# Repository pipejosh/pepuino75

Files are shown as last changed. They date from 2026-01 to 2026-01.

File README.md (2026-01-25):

## Introducing the pepuino75

This is the pepuino75, a 75 percent keyboard, featuring my custom microcontroler, the pepuinoNanoV1 (https://github.com/pipejosh/pepuinoNano-devBoard), this keyboard also features a rotary encoder, design to make it as compact as possible, without lossing any of its features!

### RENDER
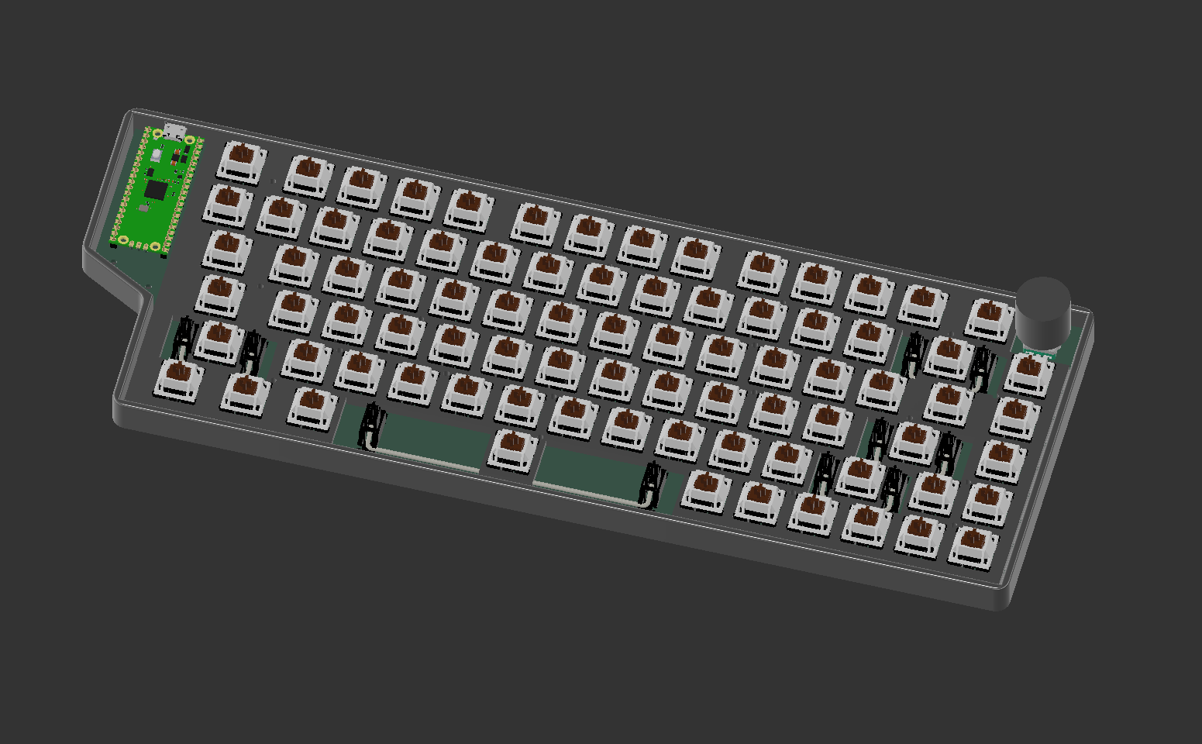
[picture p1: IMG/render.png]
 
### SCHEMATIC
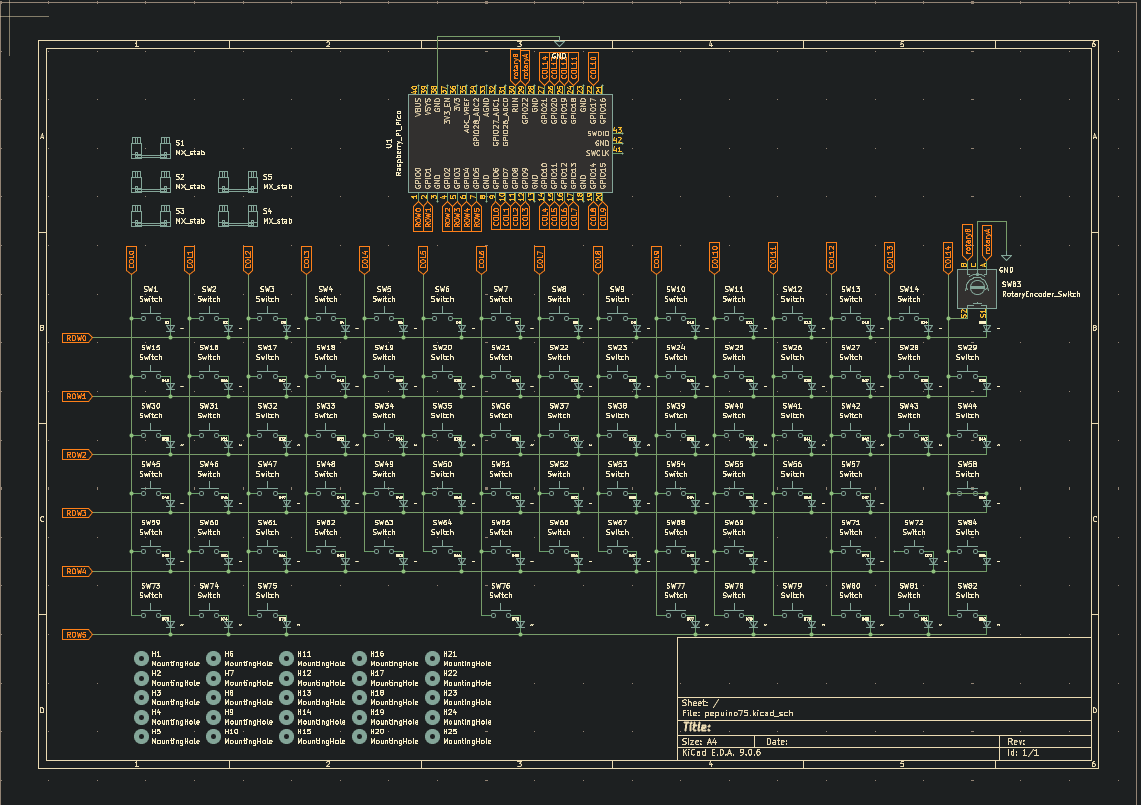
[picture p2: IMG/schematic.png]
schematic
 
### PCB
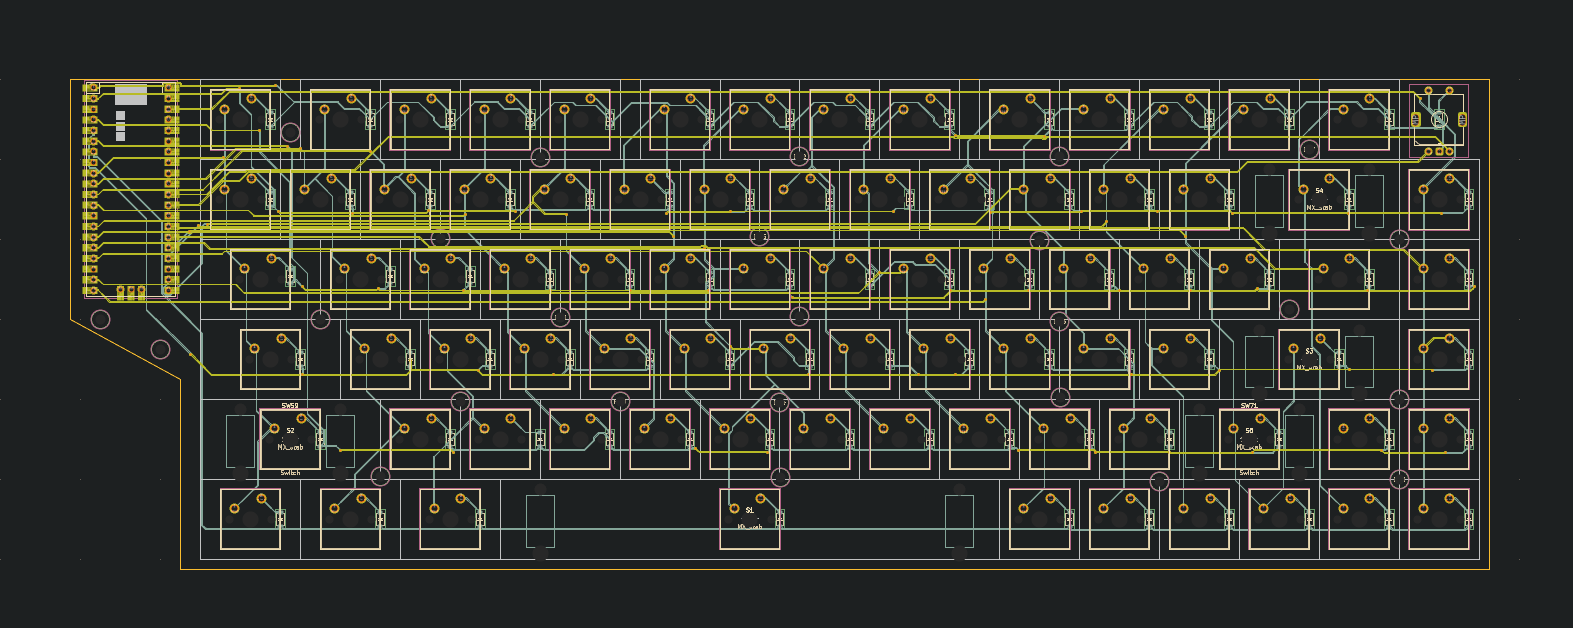
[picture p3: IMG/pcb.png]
 
### CASE
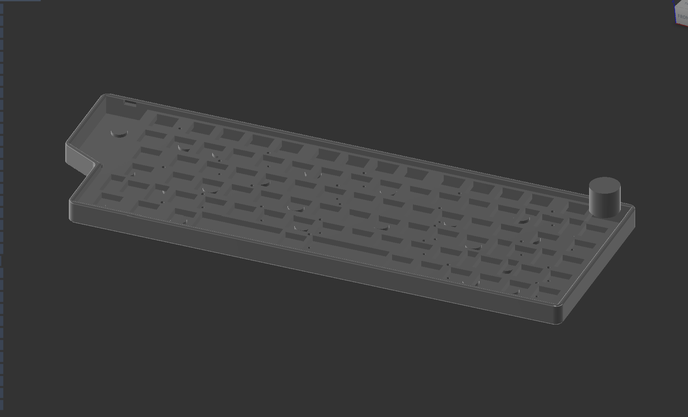
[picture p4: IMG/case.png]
case
 

### BOM
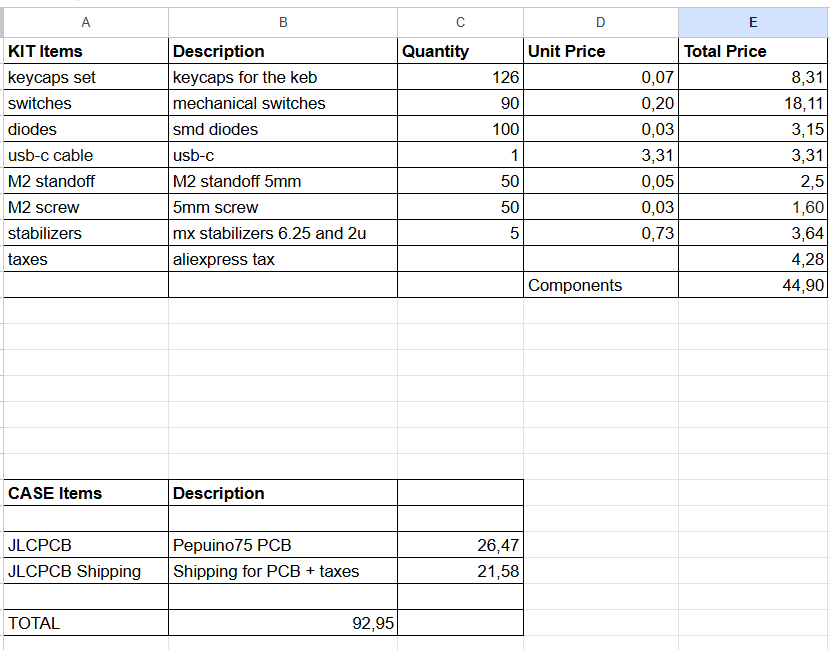
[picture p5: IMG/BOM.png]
BOM
 

## KIT Components

| Item | Description | Quantity | Unit Price | Total Price | URL |
|---|---|---:|---:|---:|---|
| Keycaps Set | Keycaps for the keyboard | 126 | 0.07 | 8.31 | https://www.aliexpress.com/item/1005007321700850.html |
| Switches | Mechanical switches | 90 | 0.20 | 18.11 | https://www.aliexpress.com/item/1005009787231480.html |
| Diodes | SMD diodes | 100 | 0.03 | 3.15 | https://www.aliexpress.com/item/1005007160563285.html |
| USB-C Cable | USB-C cable | 1 | 3.31 | 3.31 | https://www.aliexpress.com/item/1005005080440661.html |
| M2 Standoff | M2 standoff 5 mm | 50 | 0.05 | 2.50 | https://www.aliexpress.com/item/1005006049595637.html |
| M2 Screw | M2 screw 5 mm | 50 | 0.03 | 1.60 | https://www.aliexpress.com/item/1005005070119421.html |
| Stabilizers | MX stabilizers (6.25u & 2u) | 5 | 0.73 | 3.64 | https://www.aliexpress.com/item/1005007212869086.html |
| Taxes | AliExpress tax | — | — | 4.28 | — |

**KIT Components Subtotal:** 44.90

---

## PCB Costs

| Item | Description | Cost |
|---|---|---:|
| JLCPCB | Pepuino75 PCB | 26.47 |
| JLCPCB Shipping | PCB shipping + taxes | 21.58 |

**PCB Subtotal:** 48.05

---

## GRAND TOTAL

| Category | Amount |
|---|---:|
| KIT Components | 44.90 |
| PCB | 48.05 |
| **TOTAL** | **92.95** |

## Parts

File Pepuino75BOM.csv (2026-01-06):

KIT Items | Description | Quantity | Unit Price | Total Price | URL
keycaps set | keycaps for the keb | 126 | 0,07 | 8,31 | https://www.aliexpress.com/item/1005007321700850.html?spm=a2g0o.detail.0.0.6081aJsyaJsy7e&mp=1
switches | mechanical switches | 90 | 0,20 | 18,11 | https://www.aliexpress.com/item/1005009787231480.html?spm=a2g0o.detail.0.0.67adNrIhNrIhyD&mp=1
diodes | smd diodes | 100 | 0,03 | 3,15 | https://www.aliexpress.com/item/1005007160563285.html?spm=a2g0o.detail.0.0.7fc4QlPlQlPlQO&mp=1
usb-c cable | usb-c | 1 | 3,31 | 3,31 | https://www.aliexpress.com/item/1005005080440661.html?spm=a2g0o.detail.0.0.7275HudaHudawS&mp=1
M2 standoff | M2 standoff 5mm | 50 | 0,05 | 2,5 | https://www.aliexpress.com/item/1005006049595637.html?spm=a2g0o.detail.0.0.3f0euhQ3uhQ3em&mp=1
M2 screw | 5mm screw | 50 | 0,03 | 1,60 | https://www.aliexpress.com/item/1005005070119421.html
stabilizers | mx stabilizers 6.25 and 2u | 5 | 0,73 | 3,64 | https://www.aliexpress.com/item/1005007212869086.html?spm=a2g0o.detail.0.0.51bctYZZtYZZMp&mp=1
taxes | aliexpress tax |  |  | 4,28
 |  |  | Components | 44,90
CASE Items | Description
JLCPCB | Pepuino75 PCB | 26,47
JLCPCB Shipping | Shipping for PCB + taxes | 21,58
TOTAL | 92,95

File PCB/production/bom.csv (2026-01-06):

Designator | Footprint | Quantity | Value | LCSC Part #
D1, D10, D11, D12, D13, D14, D15, D16, D17, D18, D19, D2, D20, D21, D22, D23, D24, D25, D26, D27, D28, D29, D3, D30, D31, D32, D33, D34, D35, D36, D37, D38, D39, D4, D40, D41, D42, D43, D44, D45, D46, D47, D48, D49, D5, D50, D51, D52, D53, D54, D55, D56, D57, D58, D59, D6, D60, D61, D62, D63, D64, D65, D66, D67, D68, D69, D7, D71, D72, D73, D74, D75, D76, D77, D78, D79, D8, D80, D81, D82, D83, D84, D9 | Diode_SOD-123 | 83 | ~
S1 | Stabilizer_MX_6.25u | 1 | MX_stab
S2, S3, S4, S5 | Stabilizer_MX_2.00u | 4 | MX_stab
SW1, SW10, SW11, SW12, SW13, SW14, SW15, SW16, SW17, SW18, SW19, SW2, SW20, SW21, SW22, SW23, SW24, SW25, SW26, SW27, SW29, SW3, SW31, SW32, SW33, SW34, SW35, SW36, SW37, SW38, SW39, SW4, SW40, SW41, SW42, SW44, SW46, SW47, SW48, SW49, SW5, SW50, SW51, SW52, SW53, SW54, SW55, SW56, SW58, SW6, SW60, SW61, SW62, SW63, SW64, SW65, SW66, SW67, SW68, SW69, SW7, SW72, SW77, SW78, SW79, SW8, SW80, SW81, SW82, SW84, SW9 | MX_PCB_1.00u | 71 | Switch
SW28 | MX_PCB_2.00u | 1 | Switch
SW30, SW43 | MX_PCB_1.50u | 2 | Switch
SW45, SW71 | MX_PCB_1.75u | 2 | Switch
SW57, SW59 | MX_PCB_2.25u | 2 | Switch
SW73, SW74, SW75 | MX_PCB_1.25u | 3 | Switch
SW76 | MX_PCB_6.25u | 1 | Switch
SW83 | ROT_Alps_EC11E-Switch | 1 | RotaryEncoder_Switch
U1 | Raspberry_Pi_Pico | 1 | Raspberry_Pi_Pico

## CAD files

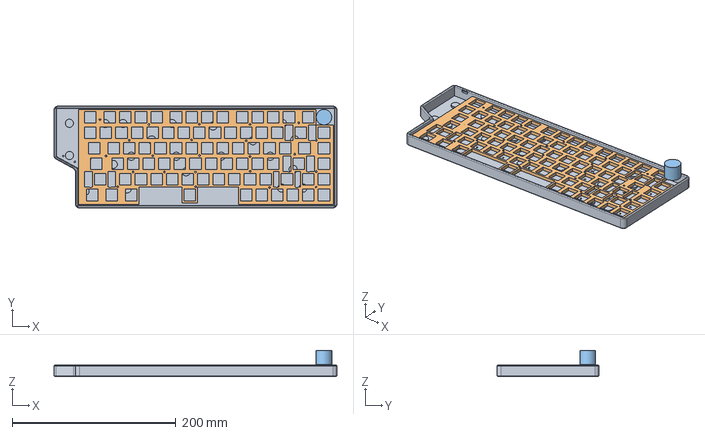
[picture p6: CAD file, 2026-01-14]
CAD/pepuino75Case.step
346.1 x 124.7 x 32.1 mm

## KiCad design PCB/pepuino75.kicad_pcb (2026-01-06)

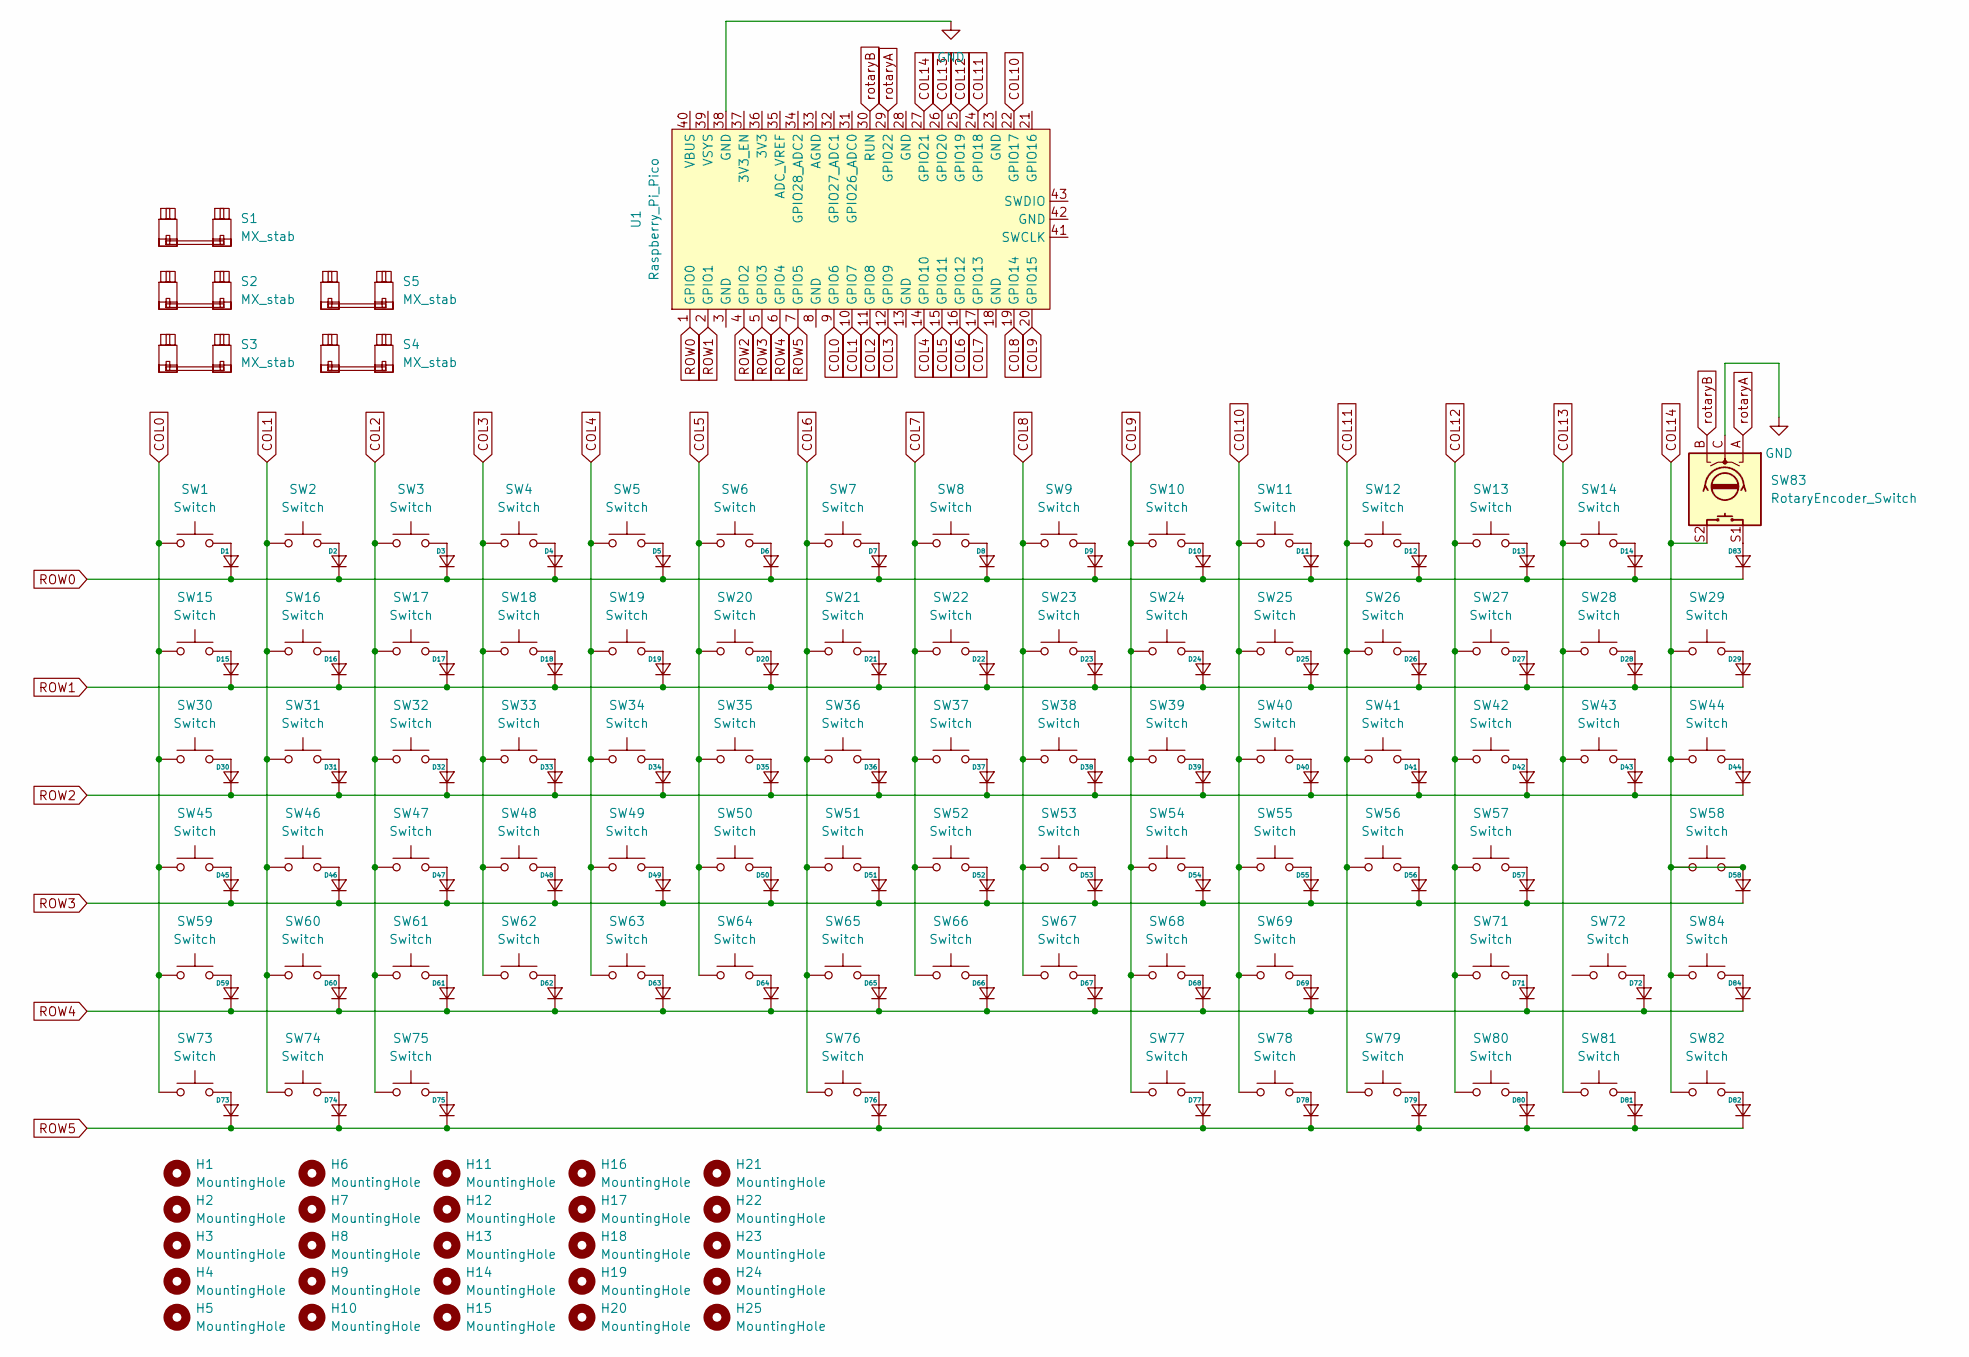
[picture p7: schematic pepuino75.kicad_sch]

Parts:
D1, D2, D3, D4, D5, D6, D7, D8, D9, D10, D11, D12, D13, D14, D15, D16, D17, D18, D19, D20, D21, D22, D23, D24, D25, D26, D27, D28, D29, D30, D31, D32, D33, D34, D35, D36, D37, D38, D39, D40, D41, D42, D43, D44, D45, D46, D47, D48, D49, D50, D51, D52, D53, D54, D55, D56, D57, D58, D59, D60, D61, D62, D63, D64, D65, D66, D67, D68, D69, D71, D72, D73, D74, D75, D76, D77, D78, D79, D80, D81, D82, D83, D84: Diode_SOD-123
H1, H2, H3, H4, H5, H6, H7, H8, H9, H10, H11, H12, H13, H14, H15, H16, H17, H18, H19, H20, H21, H22, H23, H24, H25: MountingHole; MountingHole_2.2mm_M2
S1: MX_stab; Stabilizer_MX_6.25u
S2, S3, S4, S5: MX_stab; Stabilizer_MX_2.00u
SW1, SW2, SW3, SW4, SW5, SW6, SW7, SW8, SW9, SW10, SW11, SW12, SW13, SW14, SW15, SW16, SW17, SW18, SW19, SW20, SW21, SW22, SW23, SW24, SW25, SW26, SW27, SW29, SW31, SW32, SW33, SW34, SW35, SW36, SW37, SW38, SW39, SW40, SW41, SW42, SW44, SW46, SW47, SW48, SW49, SW50, SW51, SW52, SW53, SW54, SW55, SW56, SW58, SW60, SW61, SW62, SW63, SW64, SW65, SW66, SW67, SW68, SW69, SW72, SW77, SW78, SW79, SW80, SW81, SW82, SW84: Switch; MX_PCB_1.00u
SW28: Switch; MX_PCB_2.00u
SW30, SW43: Switch; MX_PCB_1.50u
SW45, SW71: Switch; MX_PCB_1.75u
SW57, SW59: Switch; MX_PCB_2.25u
SW73, SW74, SW75: Switch; MX_PCB_1.25u
SW76: Switch; MX_PCB_6.25u
SW83: RotaryEncoder_Switch; ROT_Alps_EC11E-Switch
U1: Raspberry_Pi_Pico

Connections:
COL0: SW1.1, SW15.1, SW30.1, SW45.1, SW59.1, SW73.1, U1.9 (GPIO6)
COL1: SW2.1, SW16.1, SW31.1, SW46.1, SW60.1, SW74.1, U1.10 (GPIO7)
COL2: SW3.1, SW17.1, SW32.1, SW47.1, SW61.1, SW75.1, U1.11 (GPIO8)
COL3: SW4.1, SW18.1, SW33.1, SW48.1, SW62.1, U1.12 (GPIO9)
COL4: SW5.1, SW19.1, SW34.1, SW49.1, SW63.1, U1.14 (GPIO10)
COL5: SW6.1, SW20.1, SW35.1, SW50.1, SW64.1, U1.15 (GPIO11)
COL6: SW7.1, SW21.1, SW36.1, SW51.1, SW65.1, SW76.1, U1.16 (GPIO12)
COL7: SW8.1, SW22.1, SW37.1, SW52.1, SW66.1, U1.17 (GPIO13)
COL8: SW9.1, SW23.1, SW38.1, SW53.1, SW67.1, U1.19 (GPIO14)
COL9: SW10.1, SW24.1, SW39.1, SW54.1, SW68.1, SW77.1, U1.20 (GPIO15)
COL10: SW11.1, SW25.1, SW40.1, SW55.1, SW69.1, SW78.1, U1.22 (GPIO17)
COL11: SW12.1, SW26.1, SW41.1, SW56.1, SW79.1, U1.24 (GPIO18)
COL12: SW13.1, SW27.1, SW42.1, SW57.1, SW71.1, SW80.1, U1.25 (GPIO19)
COL13: SW14.1, SW28.1, SW43.1, SW81.1, U1.26 (GPIO20)
COL14: D58.2 (A), SW29.1, SW44.1, SW58.1, SW58.2, SW82.1, SW83.S2, SW84.1, U1.27 (GPIO21)
GND: SW83.C, U1.38 (GND)
unnamed: D1.2 (A), SW1.2
unnamed: D2.2 (A), SW2.2
unnamed: D3.2 (A), SW3.2
unnamed: D4.2 (A), SW4.2
unnamed: D5.2 (A), SW5.2
unnamed: D6.2 (A), SW6.2
unnamed: D7.2 (A), SW7.2
unnamed: D8.2 (A), SW8.2
unnamed: D9.2 (A), SW9.2
unnamed: D10.2 (A), SW10.2
unnamed: D11.2 (A), SW11.2
unnamed: D12.2 (A), SW12.2
unnamed: D13.2 (A), SW13.2
unnamed: D14.2 (A), SW14.2
unnamed: D15.2 (A), SW15.2
unnamed: D16.2 (A), SW16.2
unnamed: D17.2 (A), SW17.2
unnamed: D18.2 (A), SW18.2
unnamed: D19.2 (A), SW19.2
unnamed: D20.2 (A), SW20.2
unnamed: D21.2 (A), SW21.2
unnamed: D22.2 (A), SW22.2
unnamed: D23.2 (A), SW23.2
unnamed: D24.2 (A), SW24.2
unnamed: D25.2 (A), SW25.2
unnamed: D26.2 (A), SW26.2
unnamed: D27.2 (A), SW27.2
unnamed: D28.2 (A), SW28.2
unnamed: D29.2 (A), SW29.2
unnamed: D30.2 (A), SW30.2
unnamed: D31.2 (A), SW31.2
unnamed: D32.2 (A), SW32.2
unnamed: D33.2 (A), SW33.2
unnamed: D34.2 (A), SW34.2
unnamed: D35.2 (A), SW35.2
unnamed: D36.2 (A), SW36.2
unnamed: D37.2 (A), SW37.2
unnamed: D38.2 (A), SW38.2
unnamed: D39.2 (A), SW39.2
unnamed: D40.2 (A), SW40.2
unnamed: D41.2 (A), SW41.2
unnamed: D42.2 (A), SW42.2
unnamed: D43.2 (A), SW43.2
unnamed: D44.2 (A), SW44.2
unnamed: D45.2 (A), SW45.2
unnamed: D46.2 (A), SW46.2
unnamed: D47.2 (A), SW47.2
unnamed: D48.2 (A), SW48.2
unnamed: D49.2 (A), SW49.2
unnamed: D50.2 (A), SW50.2
unnamed: D51.2 (A), SW51.2
unnamed: D52.2 (A), SW52.2
unnamed: D53.2 (A), SW53.2
unnamed: D54.2 (A), SW54.2
unnamed: D55.2 (A), SW55.2
unnamed: D56.2 (A), SW56.2
unnamed: D57.2 (A), SW57.2
unnamed: D59.2 (A), SW59.2
unnamed: D60.2 (A), SW60.2
unnamed: D61.2 (A), SW61.2
unnamed: D62.2 (A), SW62.2
unnamed: D63.2 (A), SW63.2
unnamed: D64.2 (A), SW64.2
unnamed: D65.2 (A), SW65.2
unnamed: D66.2 (A), SW66.2
unnamed: D67.2 (A), SW67.2
unnamed: D68.2 (A), SW68.2
unnamed: D69.2 (A), SW69.2
unnamed: D71.2 (A), SW71.2
unnamed: D72.2 (A), SW72.2
unnamed: D73.2 (A), SW73.2
unnamed: D74.2 (A), SW74.2
unnamed: D75.2 (A), SW75.2
unnamed: D76.2 (A), SW76.2
unnamed: D77.2 (A), SW77.2
unnamed: D78.2 (A), SW78.2
unnamed: D79.2 (A), SW79.2
unnamed: D80.2 (A), SW80.2
unnamed: D81.2 (A), SW81.2
unnamed: D82.2 (A), SW82.2
unnamed: D83.2 (A), SW83.S1
unnamed: D84.2 (A), SW84.2
ROW0: D1.1 (K), D2.1 (K), D3.1 (K), D4.1 (K), D5.1 (K), D6.1 (K), D7.1 (K), D8.1 (K), D9.1 (K), D10.1 (K), D11.1 (K), D12.1 (K), D13.1 (K), D14.1 (K), D83.1 (K), U1.1 (GPIO0)
ROW1: D15.1 (K), D16.1 (K), D17.1 (K), D18.1 (K), D19.1 (K), D20.1 (K), D21.1 (K), D22.1 (K), D23.1 (K), D24.1 (K), D25.1 (K), D26.1 (K), D27.1 (K), D28.1 (K), D29.1 (K), U1.2 (GPIO1)
ROW2: D30.1 (K), D31.1 (K), D32.1 (K), D33.1 (K), D34.1 (K), D35.1 (K), D36.1 (K), D37.1 (K), D38.1 (K), D39.1 (K), D40.1 (K), D41.1 (K), D42.1 (K), D43.1 (K), D44.1 (K), U1.4 (GPIO2)
ROW3: D45.1 (K), D46.1 (K), D47.1 (K), D48.1 (K), D49.1 (K), D50.1 (K), D51.1 (K), D52.1 (K), D53.1 (K), D54.1 (K), D55.1 (K), D56.1 (K), D57.1 (K), D58.1 (K), U1.5 (GPIO3)
ROW4: D59.1 (K), D60.1 (K), D61.1 (K), D62.1 (K), D63.1 (K), D64.1 (K), D65.1 (K), D66.1 (K), D67.1 (K), D68.1 (K), D69.1 (K), D71.1 (K), D72.1 (K), D84.1 (K), U1.6 (GPIO4)
ROW5: D73.1 (K), D74.1 (K), D75.1 (K), D76.1 (K), D77.1 (K), D78.1 (K), D79.1 (K), D80.1 (K), D81.1 (K), D82.1 (K), U1.7 (GPIO5)
rotaryA: SW83.A, U1.29 (GPIO22)
rotaryB: SW83.B, U1.30 (RUN)

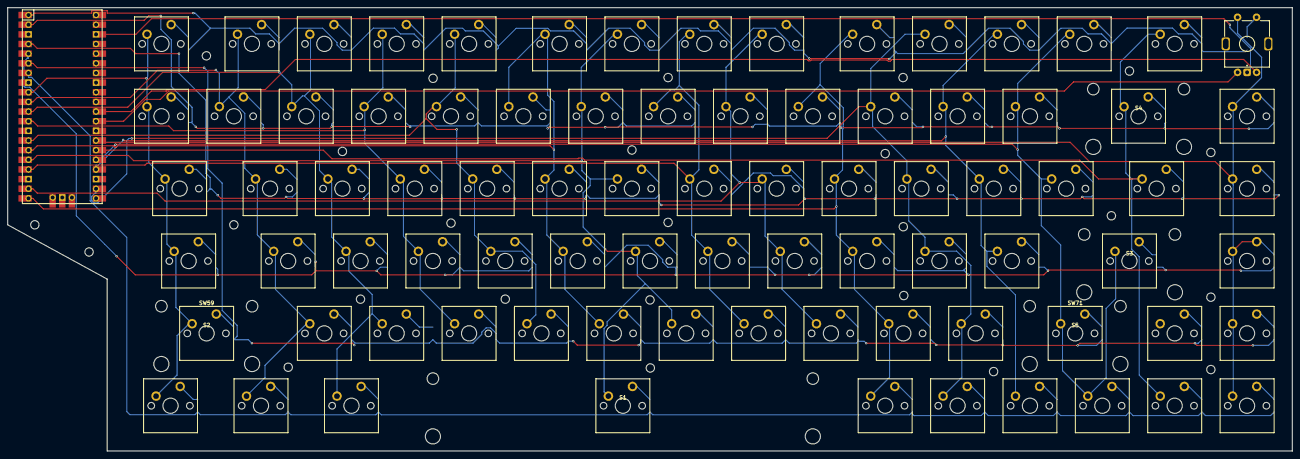
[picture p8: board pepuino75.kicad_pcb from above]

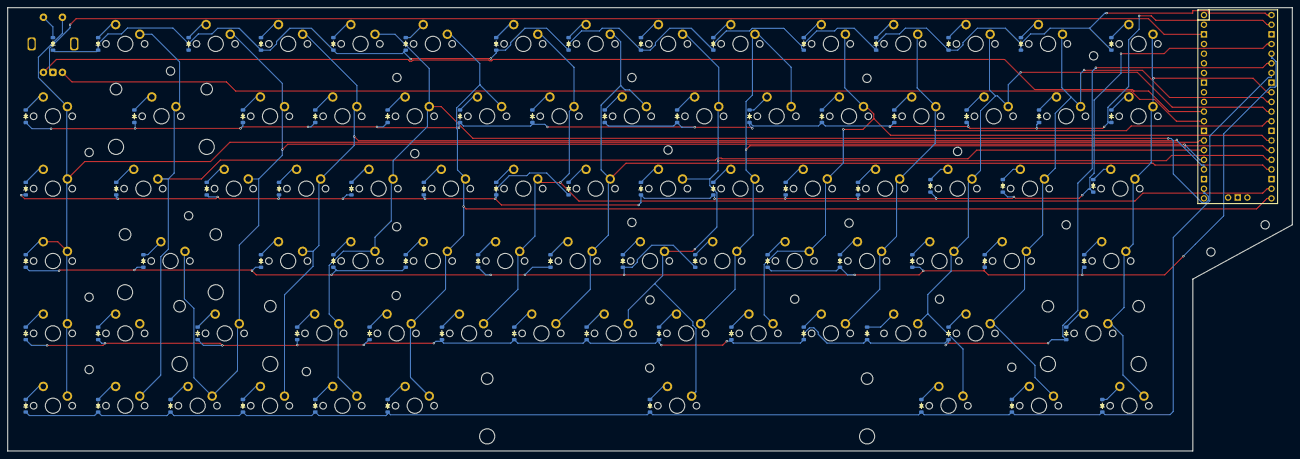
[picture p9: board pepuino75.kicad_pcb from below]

Board: 2 copper layers, 338.1 x 116.7 mm, 197 parts (83 on the bottom side), 106 nets.

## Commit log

2026-01-06 project files
    [Pepuino75BOM.csv, bom.csv, designators.csv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]
2026-01-14 add firmware + add new images + redesign the case
    [pepuino75Case.step]
2026-01-25 Revise README structure and update BOM details
    Reorganized sections in README for clarity and updated BOM with detailed item descriptions and URLs.
2026-01-25 Revise README for improved structure and clarity
    Updated the README to enhance formatting and clarity, including a structured BOM and PCB costs section.
